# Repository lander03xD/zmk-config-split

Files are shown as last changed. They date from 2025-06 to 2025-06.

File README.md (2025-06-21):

# ZMK-CONFIG-SPLIT 

This is a keyboard made with a pcb in a split layout with 36 keys and a promicro nrf52840 as the microcontroller.

zmk documentation: zmk.dev
todo: add picture of keyboard

# LAYOUT

There are by default 4 layers and 2 extra's if you want to add more in zmk studio:
* base 
* symbols
* navigation
* config

Documentation pdf can be found in the docs folder: [keymap_explained.pdf](https://github.com/lander03xD/zmk-config-split/blob/main/docs/keymap_explained.pdf).

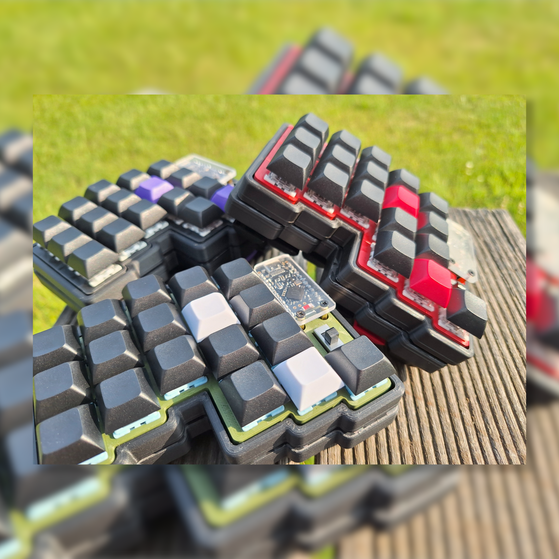
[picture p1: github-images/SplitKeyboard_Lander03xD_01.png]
Split keyboard

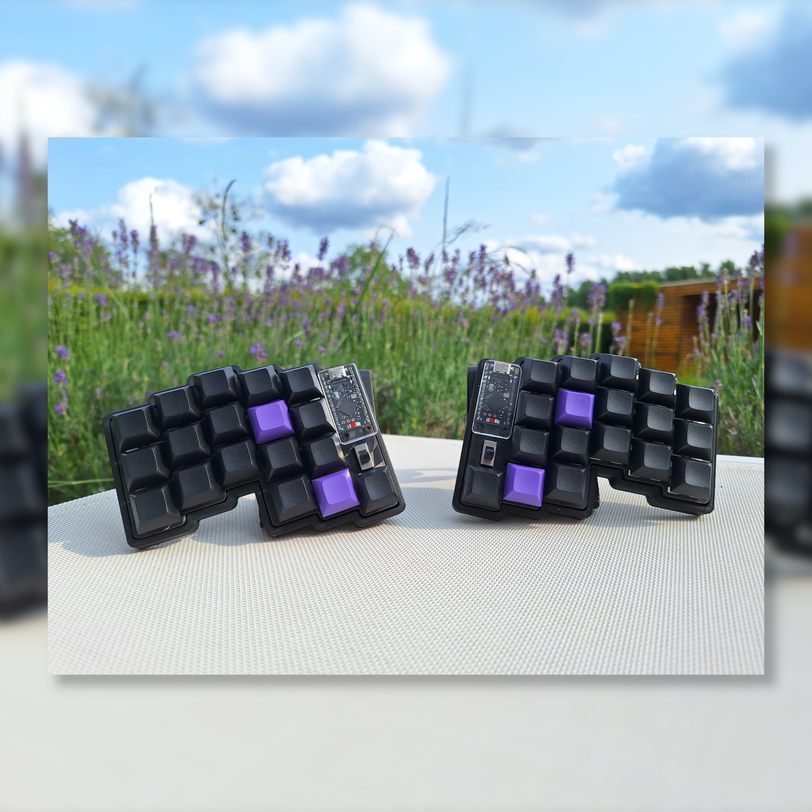
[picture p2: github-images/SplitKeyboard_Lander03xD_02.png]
Split keyboard

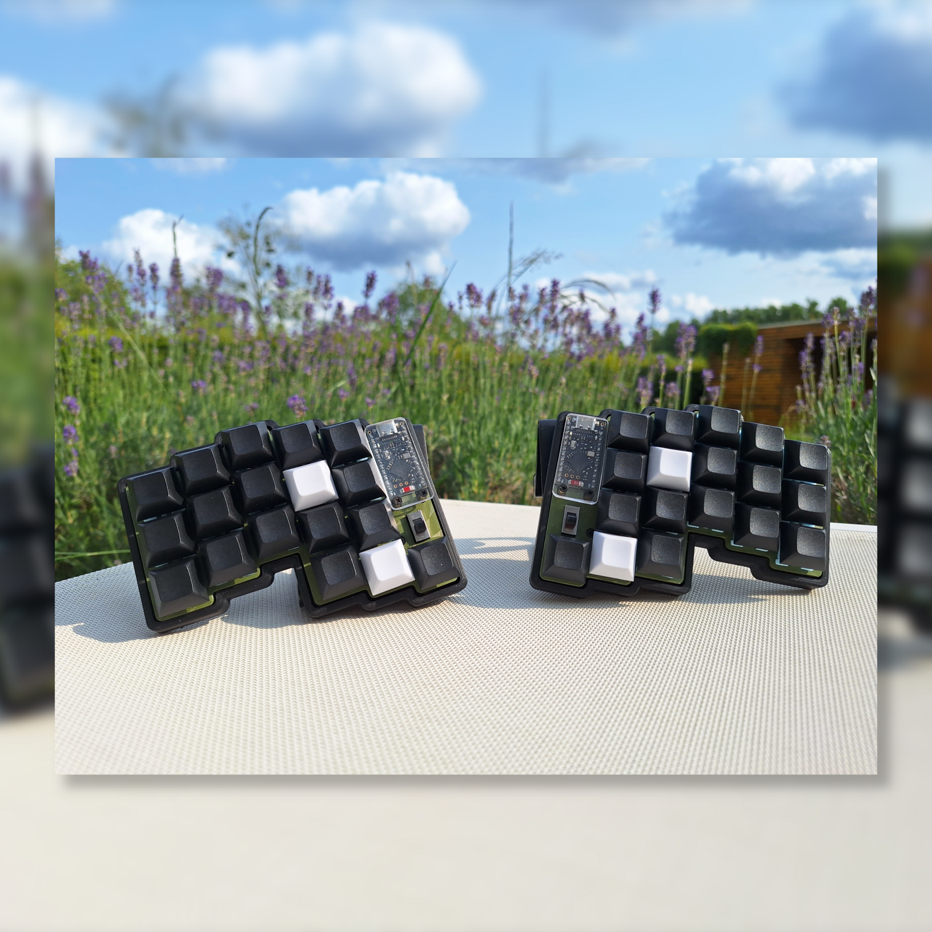
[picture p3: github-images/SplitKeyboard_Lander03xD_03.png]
Split keyboard

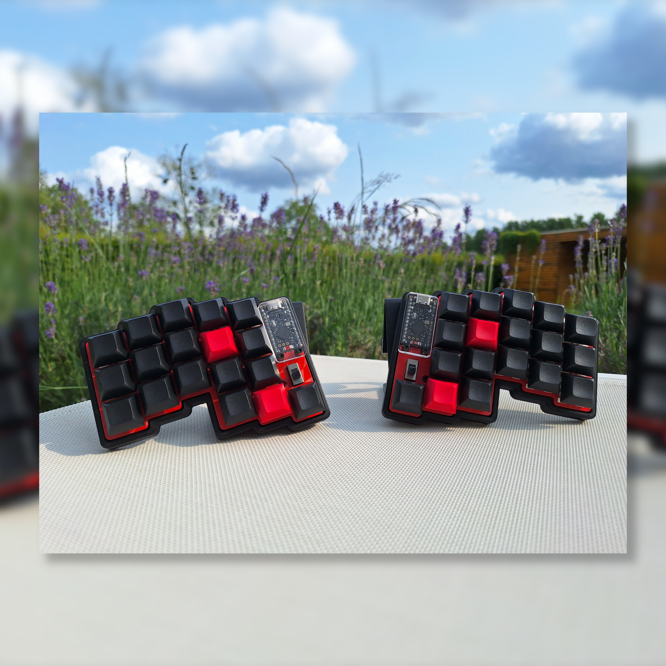
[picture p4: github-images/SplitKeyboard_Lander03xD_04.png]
Split keyboard

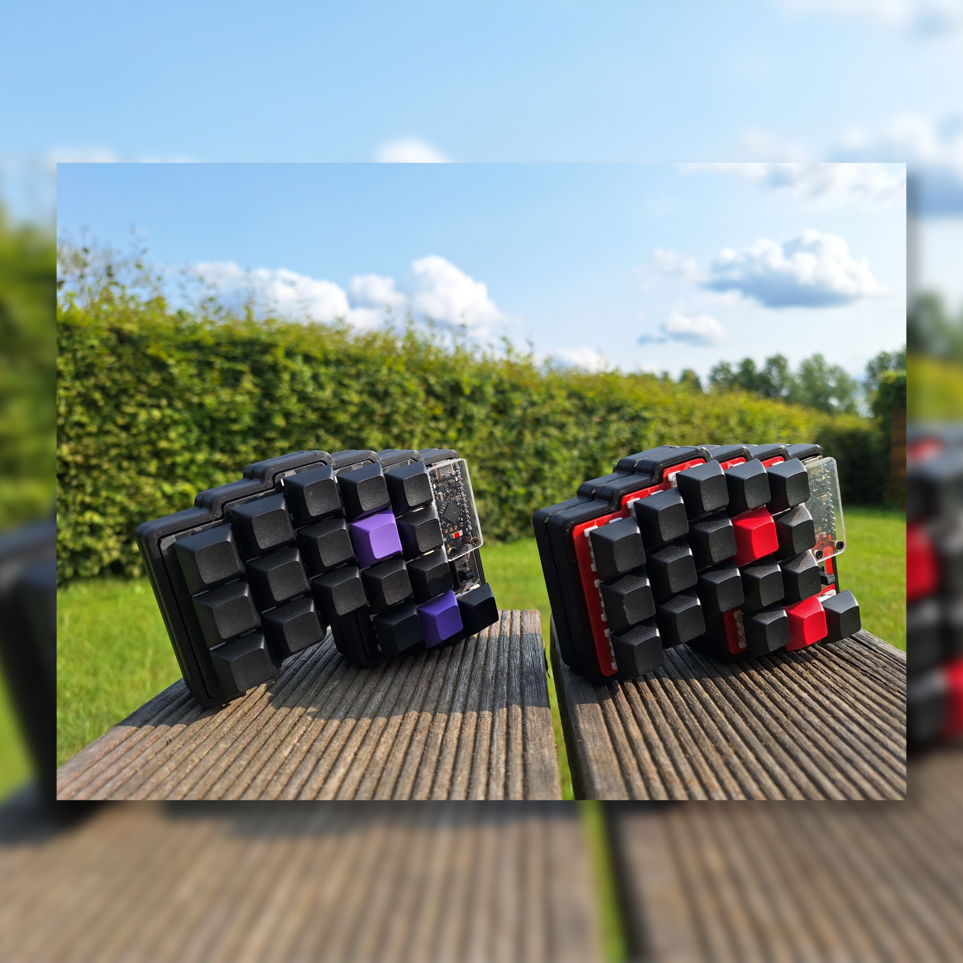
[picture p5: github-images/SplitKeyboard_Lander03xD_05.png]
Split keyboard


# Building the keyboard

This section is just for you Glen! (do ask questions)

CAUTION:
* Diodes are directional.
* Left powerlines need to be corrected.
* Always test your progress with a multimeter. 

Order of doing things:
 
* **DIODES:**
* NOTE: I put the diodes on the bottom of the board so that I can easily fix one if they are broken at some point. Diodes are directional, so put them in the right orientation.
* Bend the diodes over the powerswitch. The powerswitch is the right width so that you can easily bend the legs and insert them in the keyboard later.
* Insert all diodes. CAUTION! Diodes are directional. You can see the flow the diode allows by checking the little black line on the diode. This line should point towards the bottom of the keyboard.
* I soldered the diodes on the bottom of the board. Flip the board and solder on the legs. 
* **HEADER PINS:**
* You need a row of 12 headerpins. Count them carefully. 
* Cut off the excess. You will need the spacer on the remaining pins to lift up the edges of the microcontroller. Pull the spacers of the remaining pins and slide em on the long end of the first and last pin you will use.
* Put the diode pins on the board, and solder 1 singular pin! Reflow the solder and make sure the headerpins are straight on the PCB. If both rows of header pins are connected with a single pin. You can test out the fit with the microcontroller. before soldering in the other pins. DON'T SOLDER THE MICROCONTROLLER YET.
* **POWER SWITCH**
* Solder in the powerswitch. Orionation doens't matter. Do solder in one leg before you reflow the solder to make sure it's straight on the board.
* **FIX POWER LINES**
* On the left hand side of the boards the powerlines are not correct. These need to be corrected manually.
* cut the line going from the 'GND' pad to one of the pins. Cut the line going from the middle pin on the powerswitch to the microcontroller pin. See picture for reference.
* prepare 2 lengths of wire. Red is positive, black is gnd. solder on the back of the board.
* black: from the 'gnd' pad to the third pin on the right side. 
* red: from the middle pin on the powerswitch to the top pin on the left. 
* **BATTERY**
* pretin the battery pads
* disconnect the powerswitch. (down is 'off', up is 'on')
* solder the black wire of the battery to the 'gnd' pad, and the red wire to the 'B+' pad.
* **FIRMWARE**
* flashing the firmware. 
* connect the microcontroller to the pc. Short the 'gnd' and 'rst' pins (third and fourth pin on the right side) (acts as a reset button) swiftly twice. (check pinout : https://holykeebs.com/cdn/shop/files/Supermini-nRF52840-Pinout.webp )
* The orange led should start blinking and a drive should open on the computer. Drop the firmware in this drive and let it do it's thing. The led should stop blinking when the firmware is uploaded.
* Upload the left firmware to the left microcontroller, and the right to the right.
* **MCU**
* put the MCU on the headerpins on top of the battery. 
* solder in the pins. (Good luck) 
* **SWITCHES** 
* put the plate on the pcb and plop in your switches. 
* solder them on the board. 
* **TESTING**
* Connect the left side to the pc. Press some keys. Call me for debugging. 
* **DISAPPOINT**
* put on your filthy printed keycaps
* make my desappointed 
* **CASE**
* Print the case
* Put in the threaded inserts: 
* Clean up the holes in the printed case. 
* Put the threaded inserts in from the outside of the board (from the top for the plate, and the bottom for the case)
* Get your soldering iron and set it to 150-160C (should be enough to make pla moldable)
* push in the threaded insert with the soldering iron and press it flat with something else so it's very straight.
* **SCREWS AND STANDOFFS**
* Near the microcontroller there are 2 holes. Push some short screws in there and tighten a spacer on top.
* Put the acrylic cover on top and tighten with the other short screws.
* The long screws go through the threaded inserts all the way through the threaded inserts in the case. Press the keyboard down properly while screwing in the big boys. 

* **DONE**

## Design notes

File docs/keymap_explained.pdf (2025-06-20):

E | I
W | R

BASE
U | O
Q | T | Y | P
A | G | H
D | K
C | ,
S | F | J | L
| | | ;
X | V | M | . &mt
LGUI Z | B | N | &mt LALT /
| &mo NAVI | &mt LCTRL
ENTER &mo
SYMB | &mt | SPACE
LCTRL
TAB

LSHFT

Notes:
1) &mt is a label in zmk and stands for “mod-tap”. When held the key acts as a modifier. When tapped it acts as a keypress .
2) &mo is a label in zmk and stands for “momentary”. This is a layer switching key. When held a different layer becomes ac_ve.
3) LGUI is the name for the leb gui key. This is also known as the windows key, the super key, and on mac this would be the command key.

| | \
% | &

SYMB
/ | +
` | { | } | =
~ | [ | ]
1 ! | 5 % | 6 ^
? | *
3 # | 8 *
! | ( | ) | -
2 @ | 4 $ | 7 & | 9 (

_

0 )

&none | &trans
&none | BACKSPACE
&none | &trans

Notes:
4) Number keys can be used with shib for accessing those symbols.
5) &none is a label in zmk to indicate no func_onality is set for these keys. Oben used is different layers when the key would be used to access the current layer.
6) &trans is a label in zmk and stands for “transparent”. It acts as the key is the ac_ve layer underneath.

UP | MOUSE
UP HOME | END
NAVI | MOUSE
LEFT
CLICK

MOUSE
RIGHT
ESCAPE | PAGE UP | CLICK AUDIO
VOL UP

MOUSE
SCROLL
DOWN | UP MOUSE
DOWN LEFT | RIGHT | MOUSE
LEFT

MOUSE
AUDIO | RIGHT
MUTE

PAGE
DOWN

AUDIO
VOL
DOWN

MOUSE
SCROLL
F3 | F8 | DOWN
F2 | F4 | F7 | F9
F1 | F5 | F6
F10
| &none | &trans
&none | DELETE
&none | &trans

NOTES:
7) MOUSE: These are mouse ac_ons. Other mouse buon ac_ons are available in zmk.
8) AUDIO: These are volume/audio ac_ons. Ac_ons to interact with media players are available in zmk.

&none | &none
&studio_unlock

BT
disconnect
1

CONF
&none | &none
&bootloader | BT select 1 | &none | &bootloader
BT clear all | BT select 2 | &none
BT clear | BT select 3 | &none
&none | &none
&none | &none
&none | BT disconnect 2 | &none | &none
&none | BT disconnect 3 | &none | &none

&none

&none

COMBO | &none
&none | &none
COMBO | &none

Notes:
9) &bootloader is a label in zmk to launch the bootloader of the specific board. This will only be needed if you want to flash completely new firmware. Other method to launch the bootloader is by shor_ng the ground (GND) and reset (RST) pins on the microcontroller.
10) BT: these are the Bluetooth ac_ons. Clearing out the current or all connec_ons. Selec_ng a Bluetooth profile. And disconnec_ng from that profile.
11) The COMBO keys are defined to get into this layer. When pressing both keys from any layer at the same _me (within 150ms) the CONF layer becomes ac_ve. This combo acts as a &mo label thus the layer will only be ac_ve while both keys are held down.
12) &studio_unlock is a label in zmk to unlock the zmk studio func_onality. With ZMK studio you can change the layout to your own liking without having to flash a completely new firmware. Not all func_onality can be change and the sobware itself is s_ll a work in progress.

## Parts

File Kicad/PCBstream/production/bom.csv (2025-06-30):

Designator | Footprint | Quantity | Value | LCSC Part #
B+1, GND1 | TestPoint | 2 | TestPoint
D1, D10, D11, D12, D13, D14, D15, D16, D17, D18, D2, D3, D4, D5, D6, D7, D8, D9 | Diode_DO-35 | 18 | Diode
S1, S10, S11, S12, S13, S14, S15, S16, S17, S18, S2, S3, S4, S5, S6, S7, S8, S9 | MX_Solder_1.00u_Reversible | 18 | Keyswitch
SW2 | SW_Vertical_Slide_5mm | 1 | SW_SPDT_312
U1 | Nice_Nano_V2 | 1 | Nice_Nano_V2

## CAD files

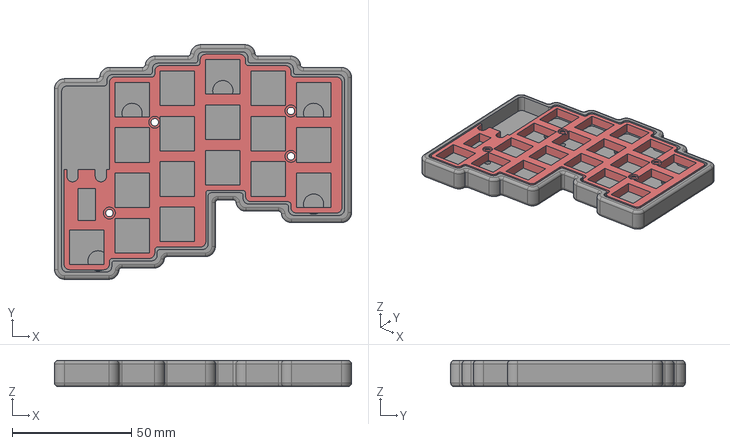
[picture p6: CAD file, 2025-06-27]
FreeCad/splitPCB.FCStd
124.7 x 98.5 x 11.0 mm
Plate
Case

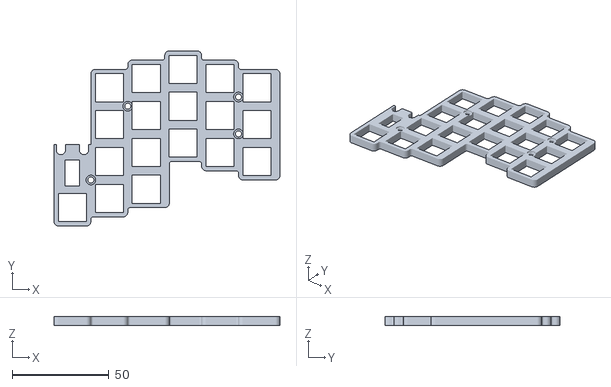
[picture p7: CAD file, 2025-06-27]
FreeCad/splitPCB-Plate.stl
116.7 x 90.5 x 4.70

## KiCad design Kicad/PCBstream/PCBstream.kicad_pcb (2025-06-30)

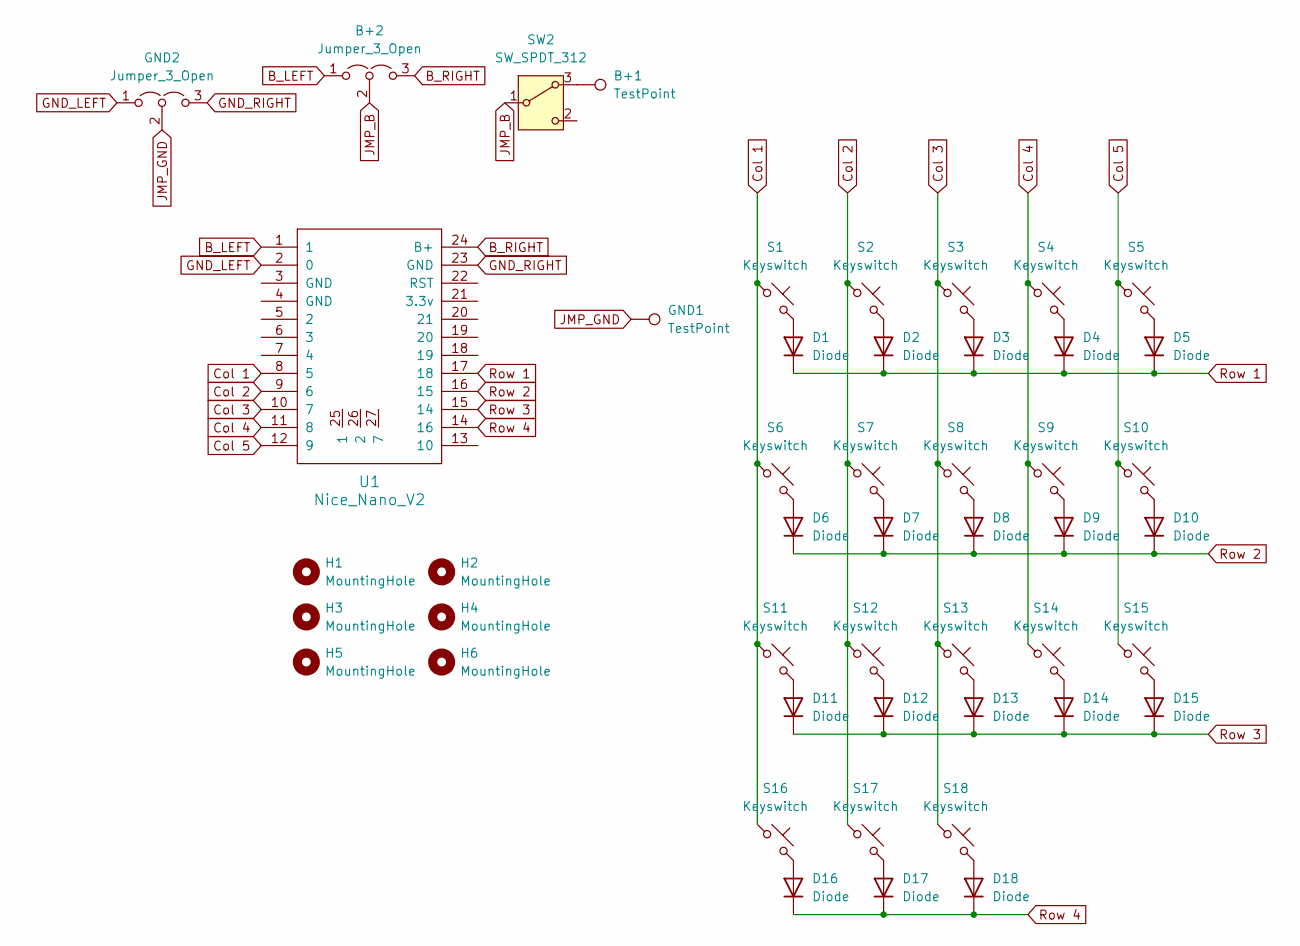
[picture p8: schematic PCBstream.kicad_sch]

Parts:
B+1: TestPoint
B+2: Jumper_3_Open; SolderWire-0.25sqmm_1x03_P4.2mm_D0.65mm_OD1.7mm
D1, D2, D3, D4, D5, D6, D7, D8, D9, D10, D11, D12, D13, D14, D15, D16, D17, D18: Diode; Diode_DO-35
GND1: TestPoint
GND2: Jumper_3_Open; SolderWire-0.25sqmm_1x03_P4.2mm_D0.65mm_OD1.7mm
H1, H2, H3, H4, H5, H6: MountingHole; MountingHole_2.2mm_M2
S1, S2, S3, S4, S5, S6, S7, S8, S9, S10, S11, S12, S13, S14, S15, S16, S17, S18: Keyswitch; MX_Solder_1.00u_Reversible
SW2: SW_SPDT_312; SW_Vertical_Slide_5mm
U1: Nice_Nano_V2

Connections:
B_LEFT: B+2.1 (A), U1.1
B_RIGHT: B+2.3 (B), U1.24 (B+)
Col 1: S1.1, S6.1, S11.1, S16.1, U1.8 (5)
Col 2: S2.1, S7.1, S12.1, S17.1, U1.9 (6)
Col 3: S3.1, S8.1, S13.1, S18.1, U1.10 (7)
Col 4: S4.1, S9.1, S14.1, U1.11 (8)
Col 5: S5.1, S10.1, S15.1, U1.12 (9)
GND_LEFT: GND2.1 (A), U1.2 (0)
GND_RIGHT: GND2.3 (B), U1.23 (GND)
JMP_B: B+2.2 (C), SW2.1 (B)
JMP_GND: GND1.1, GND2.2 (C)
unnamed: D1.2 (A), S1.2
unnamed: D2.2 (A), S2.2
unnamed: D3.2 (A), S3.2
unnamed: D4.2 (A), S4.2
unnamed: D5.2 (A), S5.2
unnamed: D6.2 (A), S6.2
unnamed: D7.2 (A), S7.2
unnamed: D8.2 (A), S8.2
unnamed: D9.2 (A), S9.2
unnamed: D10.2 (A), S10.2
unnamed: D11.2 (A), S11.2
unnamed: D12.2 (A), S12.2
unnamed: D13.2 (A), S13.2
unnamed: D14.2 (A), S14.2
unnamed: D15.2 (A), S15.2
unnamed: D16.2 (A), S16.2
unnamed: D17.2 (A), S17.2
unnamed: D18.2 (A), S18.2
unnamed: B+1.1, SW2.3 (A)
Row 1: D1.1 (K), D2.1 (K), D3.1 (K), D4.1 (K), D5.1 (K), U1.17 (18)
Row 2: D6.1 (K), D7.1 (K), D8.1 (K), D9.1 (K), D10.1 (K), U1.16 (15)
Row 3: D11.1 (K), D12.1 (K), D13.1 (K), D14.1 (K), D15.1 (K), U1.15 (14)
Row 4: D16.1 (K), D17.1 (K), D18.1 (K), U1.14 (16)

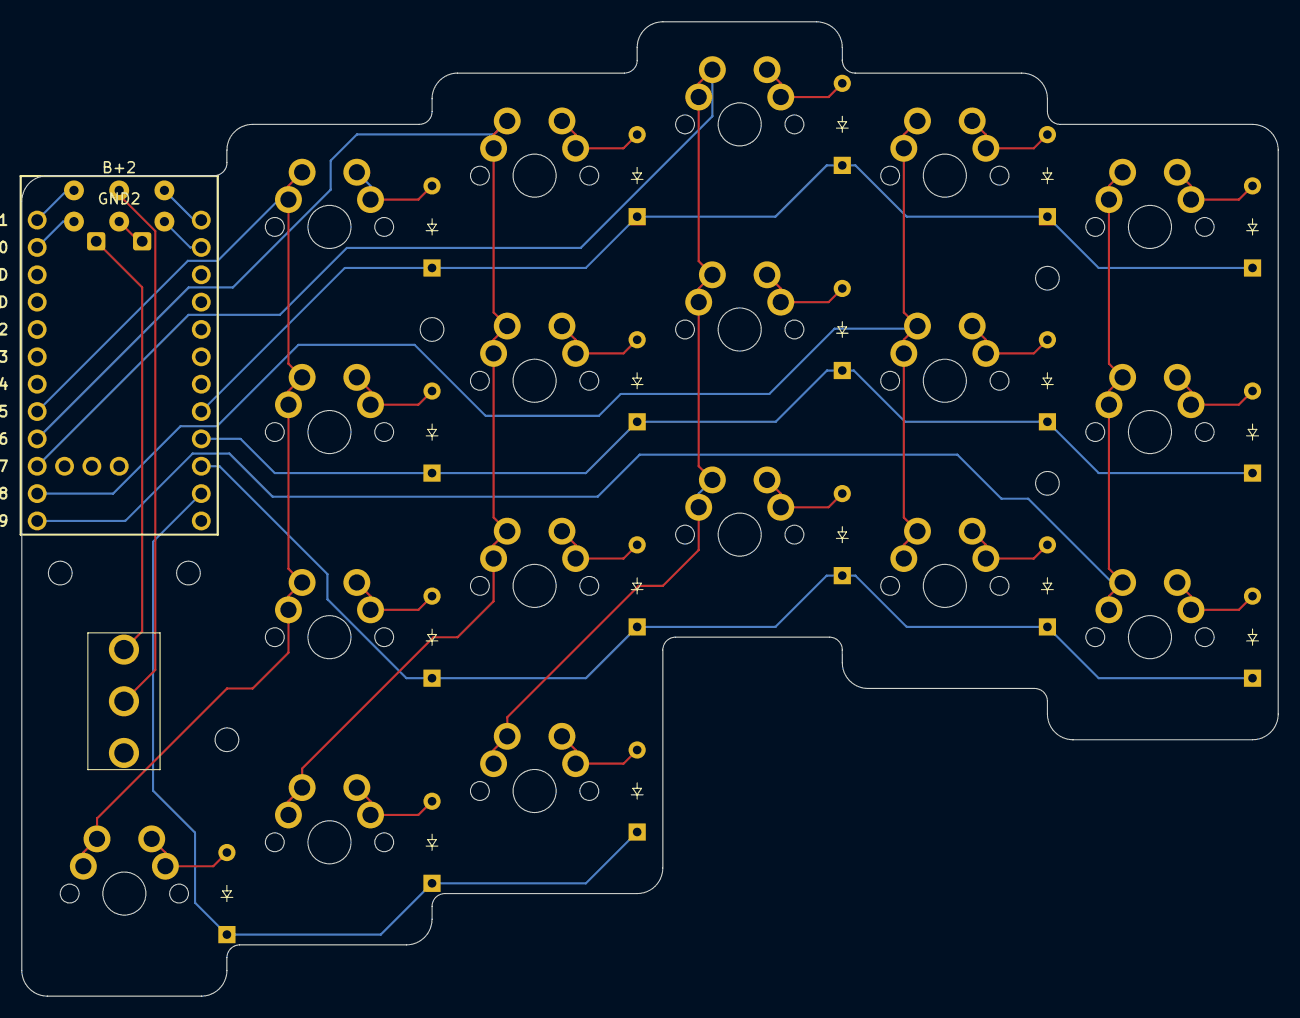
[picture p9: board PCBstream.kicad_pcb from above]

Board: 2 copper layers, 116.7 x 90.5 mm, 48 parts (0 on the bottom side), 34 nets.

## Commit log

2025-05-18 changed board
2025-05-29 added bootloader button
2025-05-30 remove reset button
2025-06-16 rename board
2025-06-27 added kicad and freecad folders
    [PCBstream.kicad_pcb, PCBstream.kicad_sch, bom.csv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]
2025-06-29 right overlay on left board
2025-06-30 updated kicad files
    [PCBstream.kicad_pcb, PCBstream.kicad_sch, bom.csv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]
2025-07-16 undo glen changes and add initial powersavings
